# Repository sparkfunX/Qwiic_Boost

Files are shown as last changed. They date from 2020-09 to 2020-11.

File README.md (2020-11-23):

Qwiic Boost
===========

Qwiic Boost

[*Qwiic Boost (SPX-17238)*](https://www.sparkfun.com/products/17238)

Qwiic Boost increases the Qwiic bus from 3.3V to 5V while still providing the target device with 3.3V I2C signals. This is a handy board for connecting technologies that still require 5V for running higher voltage mechanisms (like a DC fan) but have an internal processor running at 3.3V. We've seen this a lot with air quality sensors that use a fan to push air into a test chamber.

Repository Contents
-------------------

* **/Hardware** - Eagle design files (.brd, .sch)

License Information
-------------------

This product is _**open source**_! 

Please review the LICENSE.md file for license information. 

If you have any questions or concerns on licensing, please contact technical support on our [SparkFun forums](https://forum.sparkfun.com/viewforum.php?f=152).

Distributed as-is; no warranty is given.

- Your friends at SparkFun.

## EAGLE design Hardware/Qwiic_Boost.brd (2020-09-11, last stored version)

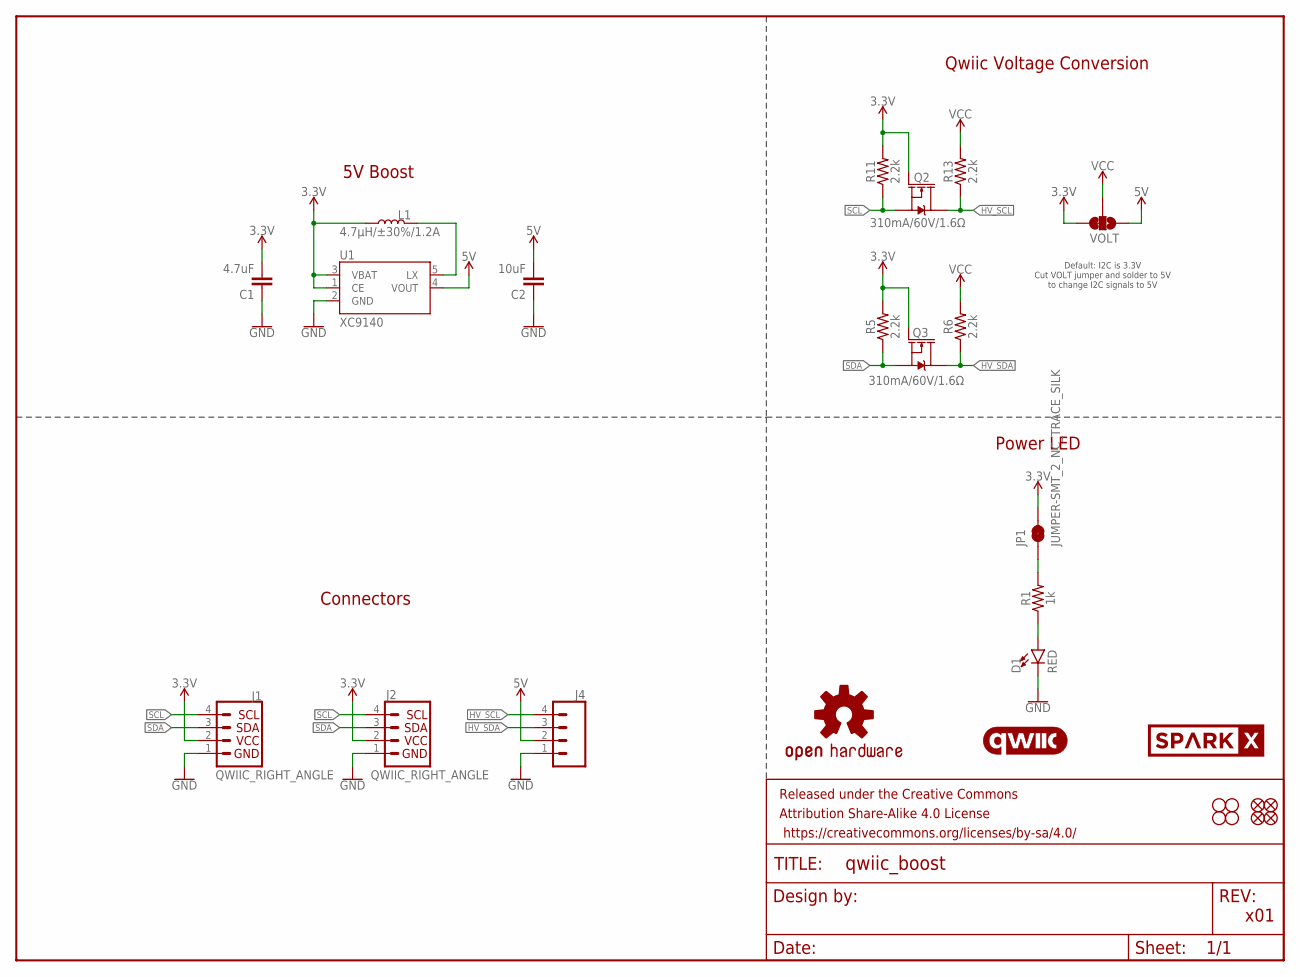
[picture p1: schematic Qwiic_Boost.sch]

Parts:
C1: 4.7uF; 0603
C2: 10uF; 0603
D1: RED; LED-0603
FD1, FD2, FD3, FD4: FIDUCIAL1X2; FIDUCIAL-1X2
FRAME1: FRAME-LETTER; CREATIVE_COMMONS
H1, H2, H3, H4: STAND-OFF
J1, J2: QWIIC_RIGHT_ANGLE; JST04_1MM_RA
J4: CONN_041X04_NO_SILK_NO_POP; 1X04_NO_SILK
JP1: JUMPER-SMT_2_NC_TRACE_SILK; SMT-JUMPER_2_NC_TRACE_SILK
L1: 4.7µH/±30%/1.2A; INDUCTOR_4.7UH
LOGO1: QWIIC_LOGO_CONNECTOR; QWIIC_5.5MM
LOGO2: OSHW-LOGOMINI; OSHW-LOGO-MINI
Q2, Q3: 310mA/60V/1.6Ω; SOT323
R1: 1k; 0603@1
R5, R6, R11, R13: 2.2k; 0603
U1: XC9140; SOT23-5
U$8: SPARKX-LOGO4; SPARKX-MEDIUM
VOLT: JUMPER-SMT_3_1-NC_TRACE_SILK; SMT-JUMPER_3_1-NC_TRACE_SILK

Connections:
3.3V: C1.2, J1.2, J2.2, JP1.2, L1.P$2 (2), Q2.1 (G), Q3.1 (G), R5.2, R11.2, U1.1 (CE), U1.3 (VBAT), VOLT.3
5V: C2.2, J4.2, U1.4 (VOUT), VOLT.1
GND: C1.1, C2.1, D1.C, J1.1, J2.1, J4.1, U1.2 (GND)
HV_SCL: J4.4, Q2.3 (D), R13.1
HV_SDA: J4.3, Q3.3 (D), R6.1
unnamed: D1.A, R1.1
unnamed: L1.P$1 (1), U1.5 (LX)
unnamed: JP1.1, R1.2
SCL: J1.4, J2.4, Q2.2 (S), R11.1
SDA: J1.3, J2.3, Q3.2 (S), R5.1
VCC: R6.2, R13.2, VOLT.2

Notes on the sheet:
Connectors
x01
5V Boost
Power LED
Qwiic Voltage Conversion
Default: I2C is 3.3V Cut VOLT jumper and solder to 5V to change I2C signals to 5V

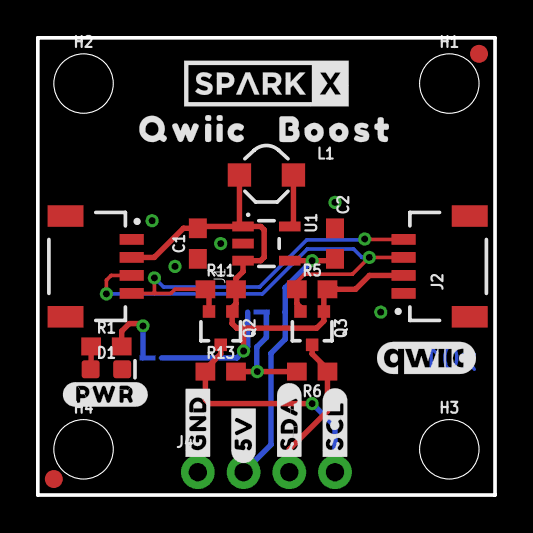
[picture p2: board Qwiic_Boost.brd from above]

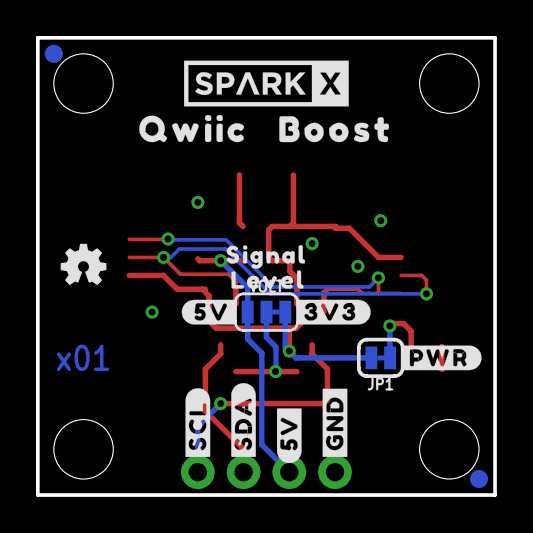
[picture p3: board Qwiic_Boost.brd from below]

Board: 2 copper layers, 25.4 x 25.4 mm, 48 parts (17 on the bottom side), 11 nets.

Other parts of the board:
U$1, U$2, U$14: #5V#3
U$3, U$4: #GND#0
U$5: #PWR#4
U$6, U$10: #SCL#2
U$7, U$9: #SDA#1
U$11, U$19: BOOST1
U$12, U$18: QWIIC0
U$13: #3V3#2
U$15: #PWR#0
U$16: LEVEL1
U$17: SIGNAL0
U$20: SPARKX-LOGO4; SPARKX-MEDIUM

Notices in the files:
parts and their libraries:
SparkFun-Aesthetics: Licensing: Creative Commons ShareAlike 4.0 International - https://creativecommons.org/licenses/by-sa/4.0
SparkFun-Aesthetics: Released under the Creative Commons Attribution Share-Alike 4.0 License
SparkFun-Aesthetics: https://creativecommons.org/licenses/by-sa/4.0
